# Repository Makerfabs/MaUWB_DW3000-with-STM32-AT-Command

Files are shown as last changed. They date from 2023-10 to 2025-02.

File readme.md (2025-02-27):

# MaUWB_DW3000 with STM32 AT Command

```

Version:    V1.3
Author:     Vincent
Create Date:    2023/10/14
Note:

    2023/10/19 V1.1: Add at command usage and hardware.
    2023/12/11 V1.2: Add a packaged position.py.
    2024/9/24  V1.3: MaUWB(v1.1.1).HEX is released to support simultaneous data transmission for ranging.

```
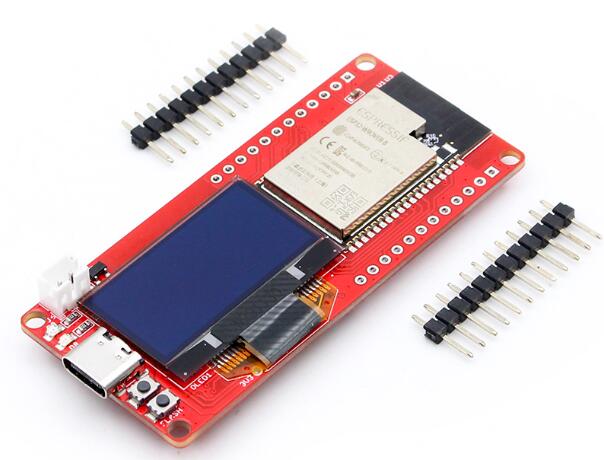
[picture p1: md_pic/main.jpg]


[toc]

# Makerfabs

[Makerfabs home page](https://www.makerfabs.com/)

[Makerfabs Wiki](https://wiki.makerfabs.com/)

# MaUWB_DW3000 with STM32 AT Command
## Intruduce

Product Link ：[MaUWB_DW3000 with STM32 AT Command](https://www.makerfabs.com/mauwb-dw3000-with-stm32-at-command.html) 

Wiki Link : [MaUWB_DW3000 with STM32 AT Command](https://wiki.makerfabs.com/%20MaUWB_DW3000-with-STM32-AT-Command.html)

The latest UWB module that solves multiple anchors& tags mutual conflicts, support max 8 Anchors + 64 tags in application, to create a multi-anchor multi-tag positioning system, and add the ability to set the Anchor antenna delay

## Feature

- DW3000 with PA, max range 500M
- Precision 0.5M(in range 100m)
- Support 8 anchors+ 64 Tags application
- Distance measurement and data transmission.

# Code

## AT Command Usage

Please refer to the AT Command manual for detailed use.

hardware\Makerfabs UWB AT Module AT Command Manual(v1.0.5).pdf

### Initial configuration

You are advised to use serial_test.ino to configure the UWB AT module.
Each time you configure the UWB AT module, follow the following configuration sequence:

```C 

AT?

//Test whether the serial port communication is normal

AT+RESTORE

//Restore factory Settings

AT+SETCFG=(x1),(x2),(x3),(x4)
// Such as: AT+SETCFG=0,1,0,1

//Set the role and frequency
//More on that later

AT+SETCAP=10,15,0

//Set the capacity and send time slot

AT+SETRPT=1

// Turn on automatic reporting

AT+SAVE

// Save

AT+RESTART

// Restart

```

### Set the role and frequency

AT+SETCFG=(x1),(x2),(x3),(x4)

Parameter description

x1: Device ID(Note: Base station 0-7, label 0-31)

x2: Device role (0: tag /1: base station)

x3: device air speed (0:850K/1:6.8M, default :6.8M)

x4: Range filtering enabled (0: off /1: on)

Generally, 850K is used and distance filtering is turned on.

```c
//Example
//A0
AT+SETCFG=0,1,0,1

//A1
AT+SETCFG=1,1,0,1

//A2
AT+SETCFG=2,1,0,1

//A3
AT+SETCFG=3,1,0,1

//T0
AT+SETCFG=0,0,0,1

//T1
AT+SETCFG=1,0,0,1

//T2
AT+SETCFG=2,0,0,1

//T3
AT+SETCFG=3,0,0,1

//T4
AT+SETCFG=4,0,0,1

//T5
AT+SETCFG=5,0,0,1

```

### Set data transmit mode

AT+SETCAP=(x1),(x2),(x3)

x1:Tag capacity (default: 10, maximum: 64)

x2:Time of a single time slot

X3:extMode (0: normal packet when communicating, 1: extended packet when communicating)

6.8M, Minimum single slot time 10ms for normal packet, Minimumsingle slot time 10ms for extended packet. 

850K. Minimum single slot time 15ms for normal packet, Minimumsingle slot time 25ms for extended packet.

```c
// 850K
AT+SETCAP=10,25,1

// 6.8M
AT+SETCAP=10,10,1

```

### Send data

Must set data transmit mode first.

AT+DATA=(x1),(x2)

x1:Length of transmitted data

x2:Transmitted data

```c

AT+DATA=32,HELLO_WORLD_123456

```

## Compiler Options

- Use type-c use cable connect USB-TTL to PC.
- Select "ESP32 DEV Module"

Libraries:
- Use 2.0.0   Wire
- Use 1.11.7   Adafruit_GFX_Library
- Use 1.14.4   Adafruit_BusIO
- Use 2.0.0   SPI
- Use 2.5.7   Adafruit_SSD1306

## Example

### esp32_at_t0

Factory firmware, reset the UWB AT module and set it to Tag 0.

### esp32_at_t0

Reset the UWB AT module and set it to Anchor 0.

### serial_test

Serial port test

### data_transmit

This command is used to test the newly added AT+DATA command, which can transmit data.

### Indoor positioning

Simple indoor positioning example, using json to pass data.
You need to configure all UWB modules in advance and burn the get_range program to A0.
This program parses the AT instructions into JSON format and uploads them through the serial port.

The corresponding Python packages, such as PySerial and PyGame, need to be installed in advance.
And modify the position of several origin points in the code:

(unit cm)
```Python

A0X, A0Y = 300, 200
A1X, A1Y = 300, 300
A2X, A2Y = 0, 0
A3X, A3Y = 0, 700

```
Connect the PC with a USB cable and run the Python program.

**This code is for promotional use only and is not part of the UWB AT module product, and Makerfabs does not provide further technical support.**

**Update**

For a more convenient experience for some customers, we provide a packaged exe file. Please insert A0 configured first, and be sure to burn the get_range program.

And make sure the computer's serial port is not connected to any other devices, because this program is scanning the first COM device.

And this program has been determined to be in the range of 10 meters by 10 meters, and will be accompanied by various crashes.

We are not responsible for any technical support for this software, for reference only, only for the packaging of position.py.

# AT Module Firmware Update

Connect ST-Link to PC.

Open STM32 ST-LINK Utility.
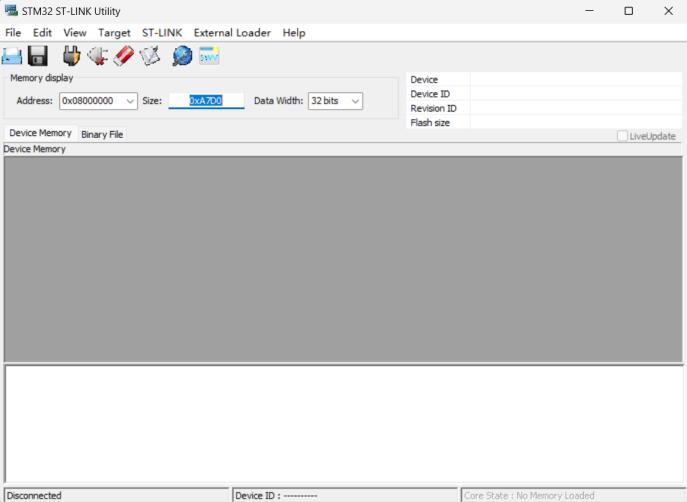
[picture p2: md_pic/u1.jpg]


Open "Target/Settings", it should display ST-Link Serial Number.
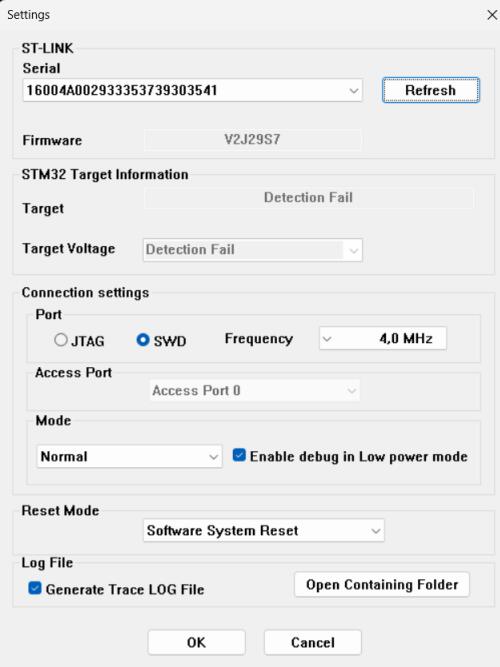
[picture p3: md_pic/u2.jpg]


Close the window, back to main page.

Connect ST-Link and MaUWB.

And use TypeC cable power on MaUWB, the power of ST-Link is not enough.

Like this:

|ST-LINK|3v3|gnd|clk|dio|
|----|----|----|----|----|
|UWB_AT|3.3v|gnd|swclk|swdio|

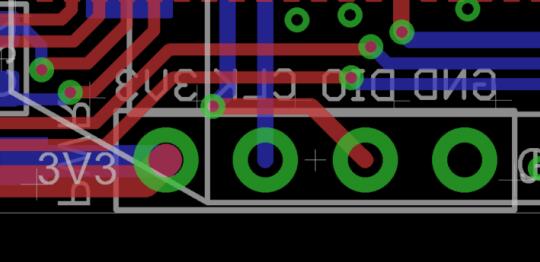
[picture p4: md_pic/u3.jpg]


Click "connect to target", it should be display device type. And click "Program verify".

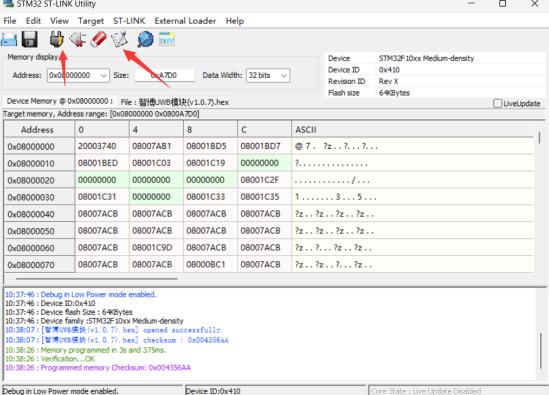
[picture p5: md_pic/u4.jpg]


Select hex file, click "START" to download.

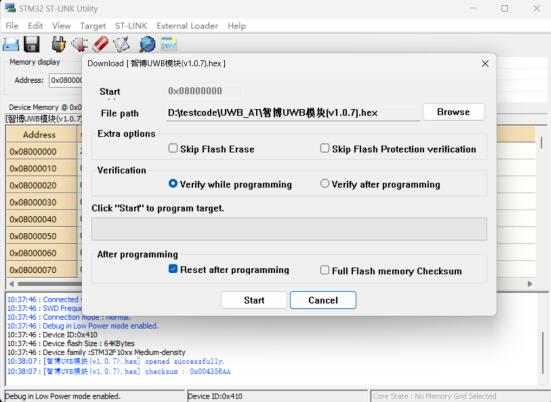
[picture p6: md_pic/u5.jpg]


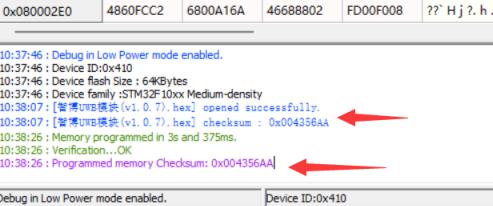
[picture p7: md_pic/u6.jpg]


# STM32 Pin Map

STM32F103RCT6

|Index|STM32|PINOUT|Function|
|----|----|----|----|
|1|PA0|DW_RSTn|Reset pin. Active Low Output.|
|2|PA4|DW_CSn|SPI chip select|
|3|PA5|DW_SLK|SPI clock|
|4|PA6|DW_MISO|SPI data output|
|5|PA7|DW_MOSI|SPI data input.|
|6|PA8|DW_EXTON|External device enable. Asserted during wake up process and held active until device enters sleep mode. Can be used to control external DC-DC converters or other circuits that are not required when the device is in sleep mode so as to minimize power consumption.|
|7|PB0|DW_wakeup|When asserted into its active high state, the WAKEUP pin brings the DW3000 out of SLEEP or DEEPSLEEP states into operational mode|
|8|PB5|DW_IRQn|Interrupt Request output from the DW3000 to the host processor. By default IRQ is an active-high output but may be configured to be active low if required. For correct operation in SLEEP and DEEPSLEEP modes it should be configured for active high operation. This pin will float in SLEEP and DEEPSLEEP states and may cause spurious interrupts unless pulled low. When the IRQ functionality is not being used the pin may be reconfigured as a general purpose I/O line, GPIO8.|
|10|PA1|LED_RUN|Indicator output pin|
|11|PA9|USART1_TX|
|12|PA10|USART1_RX|
|13|PA13|SWDIO|
|14|PA14|SWCLK|

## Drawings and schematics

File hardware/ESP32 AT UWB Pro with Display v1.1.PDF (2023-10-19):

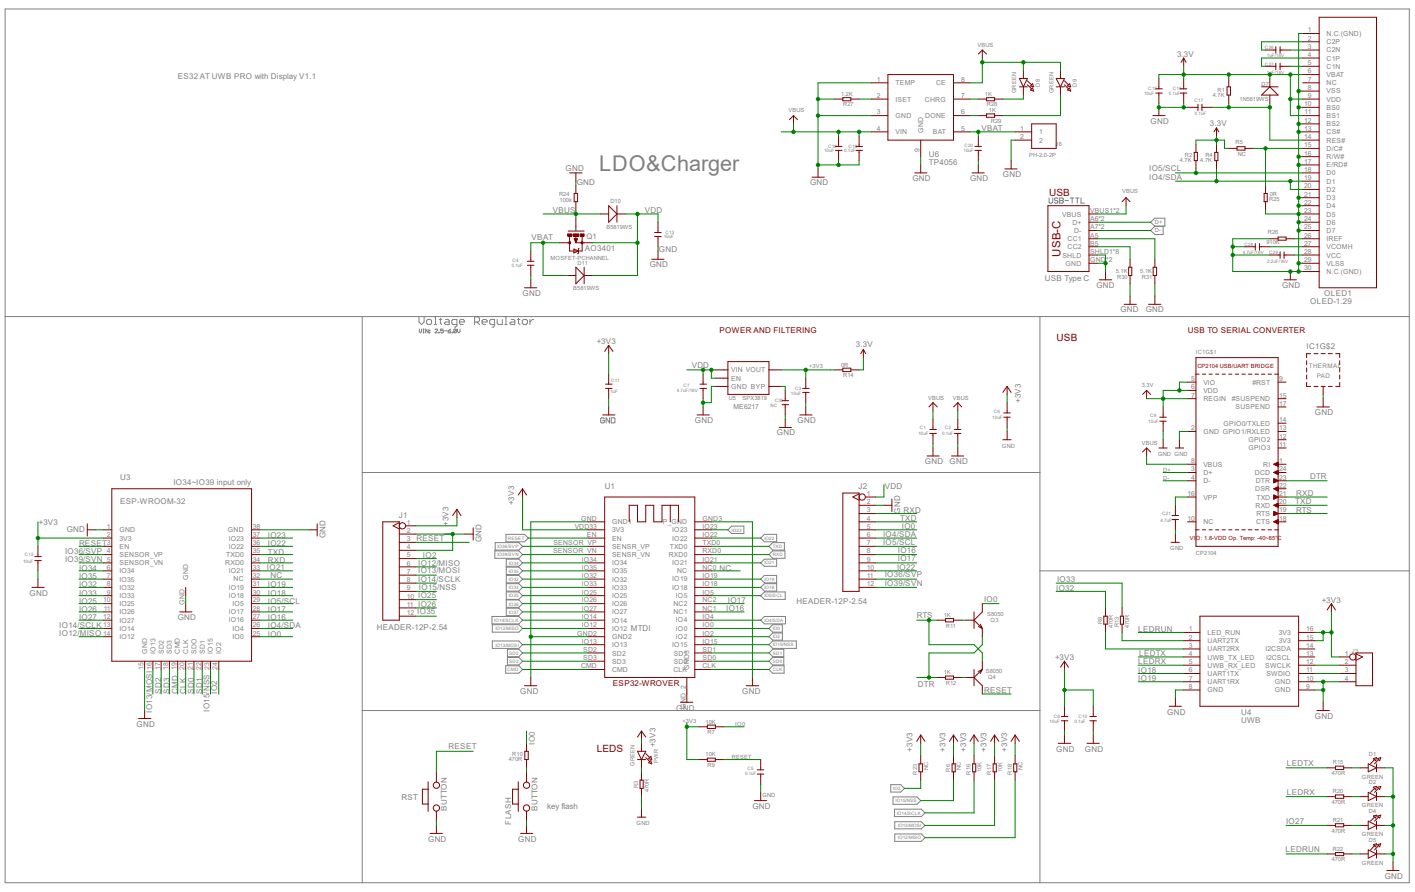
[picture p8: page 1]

ES32 AT UWB PRO with Display V1.1

USB Type C LDO&Charger

VIO: 1.8-VDD Op. Temp: -40~85°C USB⁻C

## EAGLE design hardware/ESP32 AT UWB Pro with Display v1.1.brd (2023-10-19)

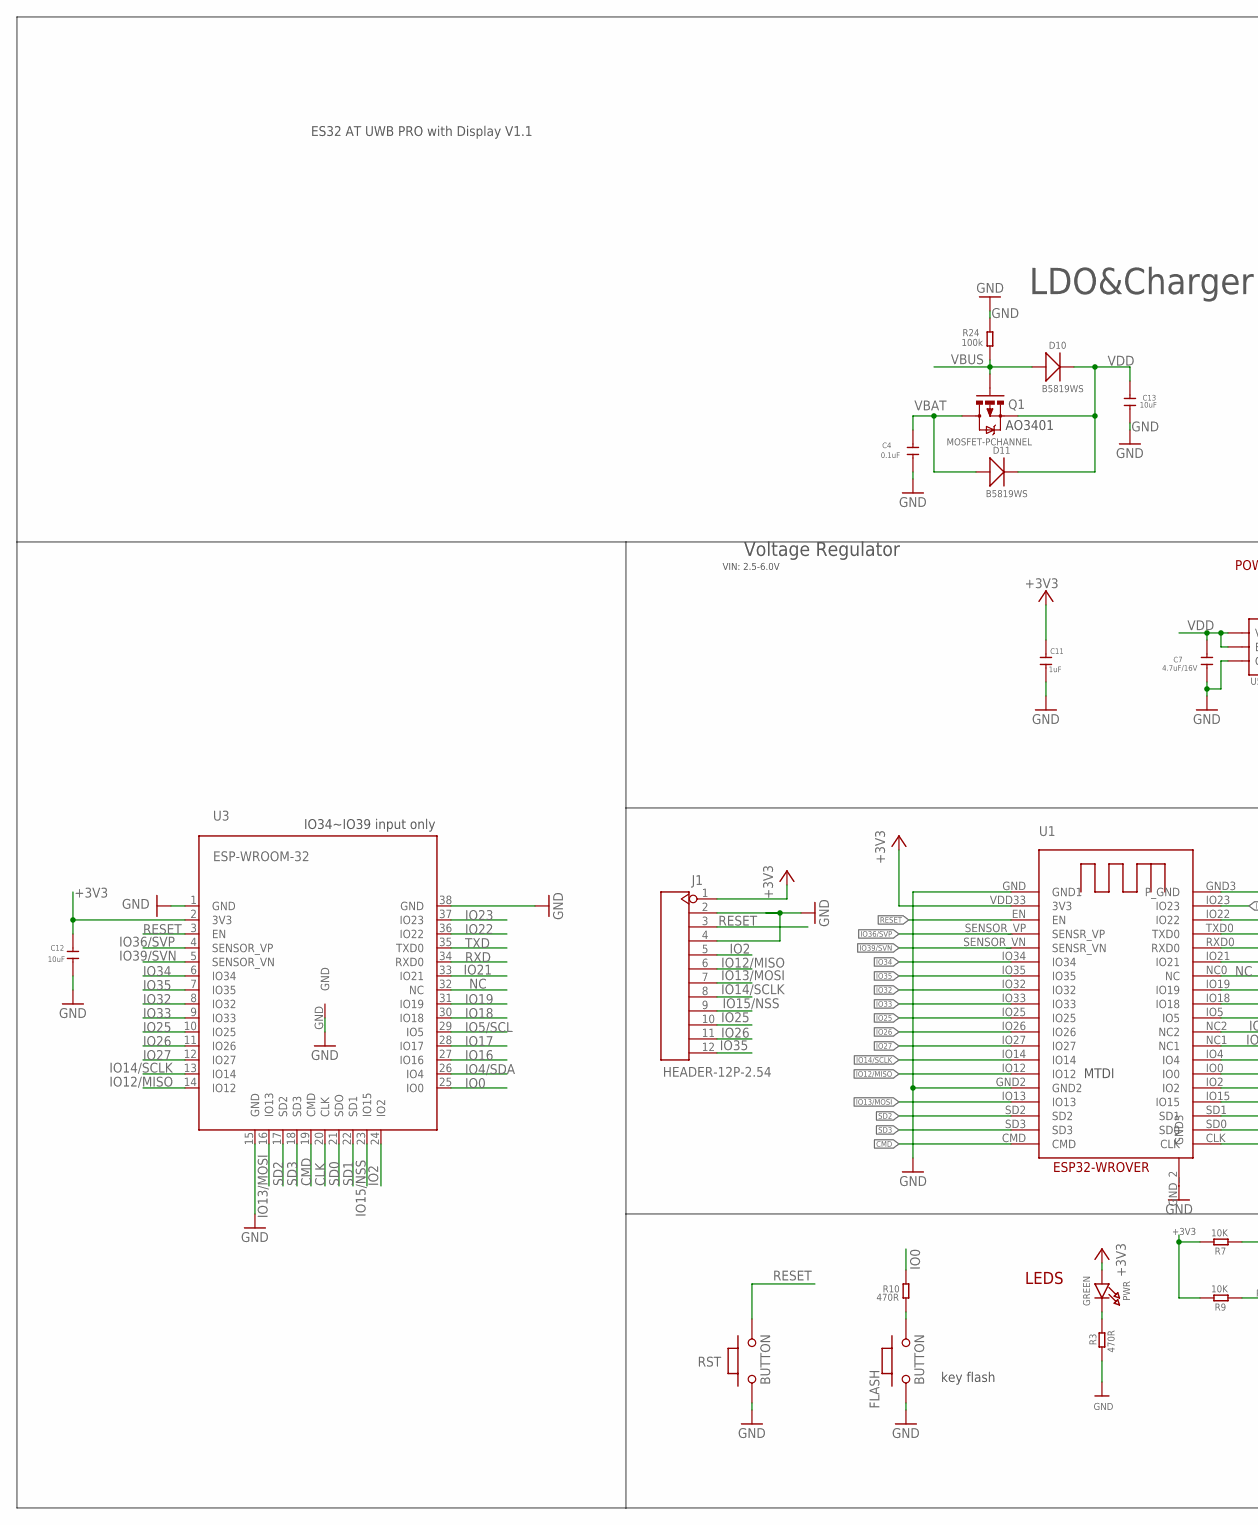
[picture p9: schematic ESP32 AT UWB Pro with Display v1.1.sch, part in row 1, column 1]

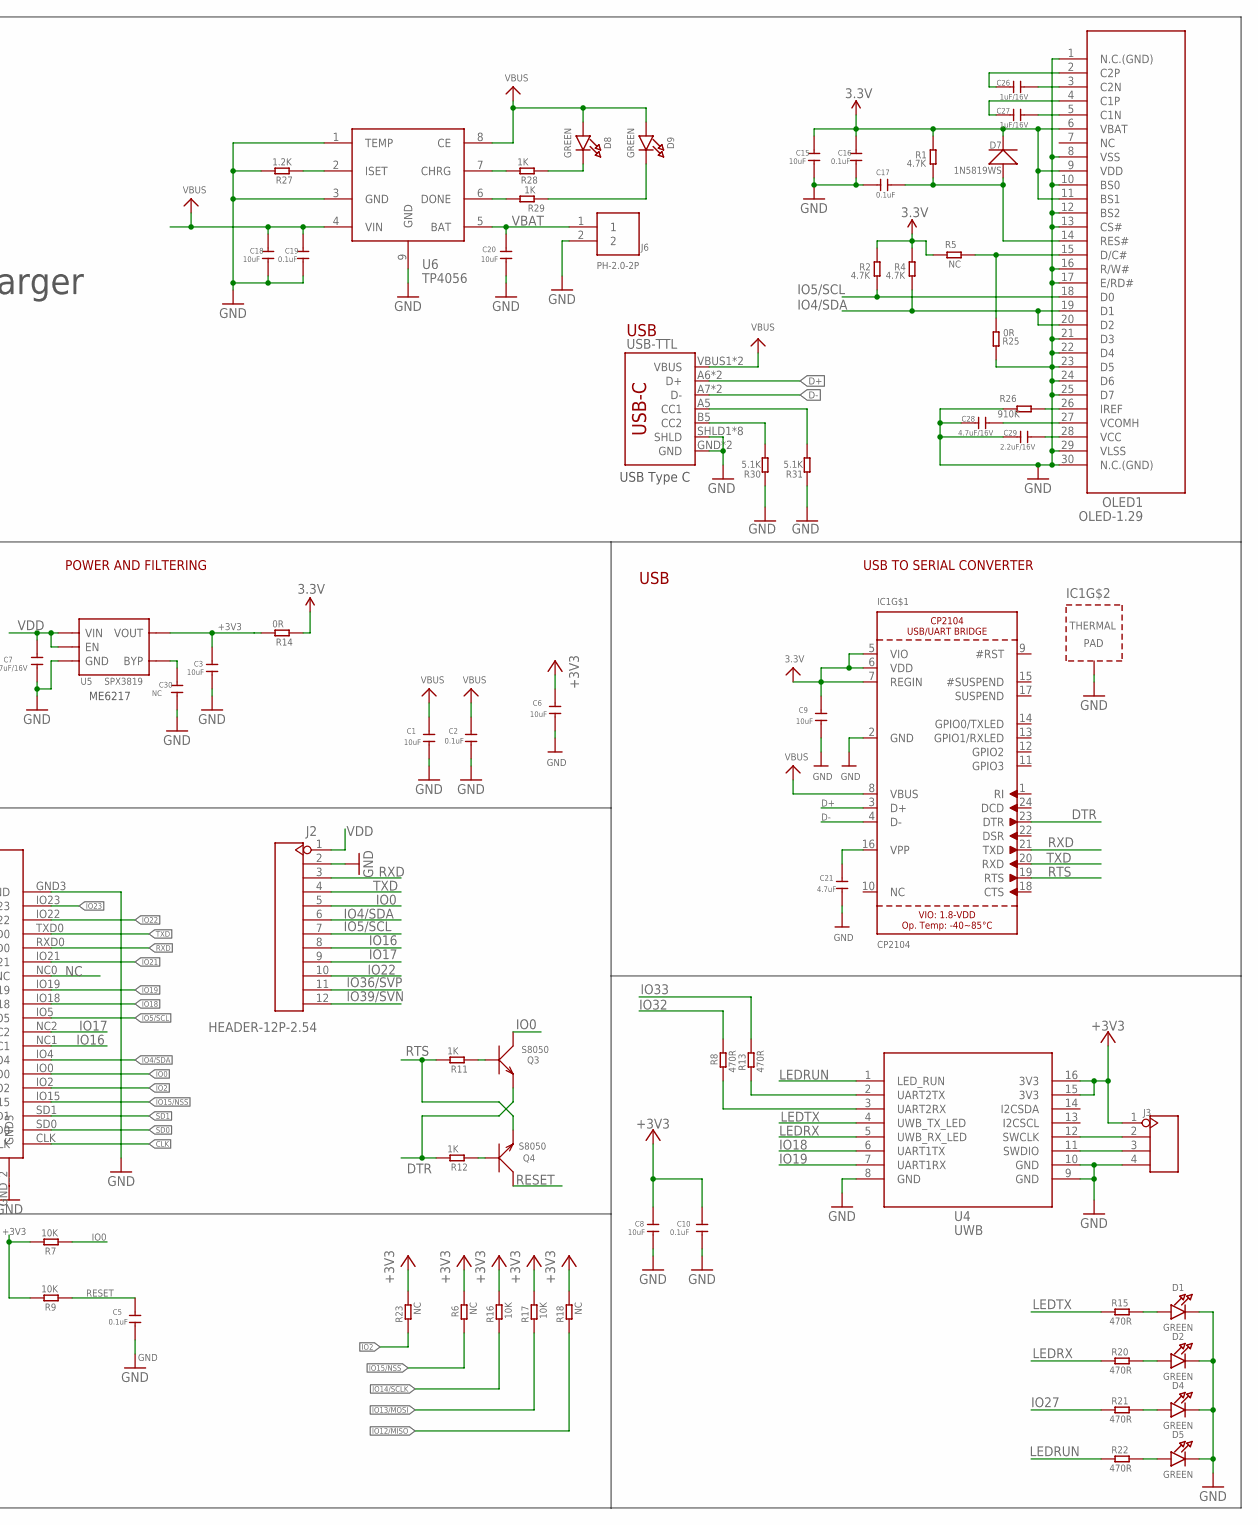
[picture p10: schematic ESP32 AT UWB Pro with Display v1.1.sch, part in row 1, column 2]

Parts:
C1, C3, C6, C8, C9, C12, C13, C15, C18, C20: 10uF; 0603
C2, C4, C5, C10, C16, C17, C19: 0.1uF; 0603
C7, C28: 4.7uF/16V; 0603
C11: 1uF; 0603
C21: 4.7uF; 0603
C26, C27: 1uF/16V; 0603
C29: 2.2uF/16V; 0603
C30: NC; 0603
D1, D2, D4, D5, D8, D9: GREEN; CHIPLED_0805_NOOUTLINE
D7: 1N5819WS; SOD323
D10, D11: B5819WS; SOD323
FLASH: BUTTON; 157SW
IC1: CP2104; QFN24_4MM_SMSC
J1, J2: HEADER-12P-2.54; 12P-2.54
J3: HEADER-4P-60/35MILROUND; 4P-65/35ROUND
J6: PH-2.0-2P
OLED1: OLED-1.29
PWR: GREEN; CHIPLED_0805_NOOUTLINE
Q1: MOSFET-PCHANNEL; SOT23-3
Q3, Q4: S8050; SOT23
R1, R2, R4: 4.7K; R0603
R3, R8, R10, R13, R15, R20, R21, R22: 470R; R0603
R5, R6, R18, R23: NC; R0603
R7, R9, R16, R17: 10K; R0603
R11, R12, R28, R29: 1K; R0603
R14, R25: 0R; R0603
R24: 100k; R0603
R26: 910K; R0603
R27: 1.2K; R0603
R30, R31: 5.1K; DISCRETE_R0603
RST: BUTTON; 157SW
U1: ESP32-WROVER
U3: ESP-WROOM-32
U4: UWB
U5: SPX3819; SOT23-5
U6: TP4056; SOP8-1.27P
USB-TTL: USB_C5; USB-C-16P-5

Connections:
3.3V: C15.1, C16.1, D7.-, OLED1.6 (VBAT), OLED1.9 (VDD), OLED1.11 (BS1), R1.2, R2.2, R4.2, R5.2, R14.1
+3V3: C3.1, C6.1, C8.1, C9.1, C10.1, C11.1, C12.1, IC1.5 (VIO), IC1.6 (VDD), IC1.7 (REGIN), J1.1, J3.1, PWR.A, R6.2, R7.2, R9.2, R14.2, R16.2, R17.2, R18.2, R23.2, U1.VDD33 (3V3), U3.2 (3V3), U4.15 (3V3), U4.16 (3V3), U5.5 (VOUT)
CLK: U1.CLK, U3.20 (CLK)
CMD: U1.CMD, U3.19 (CMD)
D+: IC1.3 (D+), USB-TTL.A6 (D+), USB-TTL.B6 (D+)
D-: IC1.4 (D-), USB-TTL.A7 (D-), USB-TTL.B7 (D-)
DTR: IC1.23 (DTR), Q3.2 (E), R12.2
GND: C1.2, C2.2, C3.2, C4.2, C5.2, C6.2, C7.2, C8.2, C9.2, C10.2, C11.2, C12.2, C13.1, C15.2, C16.2, C17.1, C18.2, C19.2, C20.2, C21.2, C28.1, C29.1, C30.2, D1.C, D2.C, D4.C, D5.C, FLASH.1, IC1.2 (GND), IC1.THERM (TP), J1.2, J1.4, J2.2, J3.4, J6.2, OLED1.1 (N.C.(GND)), OLED1.8 (VSS), OLED1.10 (BS0), OLED1.12 (BS2), OLED1.13 (CS#), OLED1.16 (R/W#), OLED1.17 (E/RD#), OLED1.21 (D3), OLED1.22 (D4), OLED1.23 (D5), OLED1.24 (D6), OLED1.25 (D7), OLED1.29 (VLSS), OLED1.30 (N.C.(GND)), R3.1, R24.2, R25.2, R26.2, R27.2, R30.1, R31.1, RST.1, U1.GND (GND1), U1.GND2, U1.GND3 (P_GND), U1.GND_2 (GND3), U3.1 (GND), U3.15 (GND), U3.38 (GND), U3.GND, U4.8 (GND), U4.9 (GND), U4.10 (GND), U5.2 (GND), U6.1 (TEMP), U6.3 (GND), U6.9 (GND), USB-TTL.GND, USB-TTL.GND2 (GND), USB-TTL.SHLD1 (SHLD), USB-TTL.SHLD2 (SHLD), USB-TTL.SHLD3 (SHLD), USB-TTL.SHLD4 (SHLD), USB-TTL.SHLD5 (SHLD), USB-TTL.SHLD6 (SHLD), USB-TTL.SHLD7 (SHLD), USB-TTL.SHLD8 (SHLD)
IO0: J2.5, Q3.3 (C), R7.1, R10.2, U1.IO0, U3.25 (IO0)
IO2: J1.5, R23.1, U1.IO2, U3.24 (IO2)
IO4/SDA: J2.6, OLED1.19 (D1), OLED1.20 (D2), R4.1, U1.IO4, U3.26 (IO4)
IO5/SCL: J2.7, OLED1.18 (D0), R2.1, U1.IO5, U3.29 (IO5)
IO12/MISO: J1.6, R18.1, U1.IO12, U3.14 (IO12)
IO13/MOSI: J1.7, R17.1, U1.IO13, U3.16 (IO13)
IO14/SCLK: J1.8, R16.1, U1.IO14, U3.13 (IO14)
IO15/NSS: J1.9, R6.1, U1.IO15, U3.23 (IO15)
IO16: J2.8, U1.NC1, U3.27 (IO16)
IO17: J2.9, U1.NC2, U3.28 (IO17)
IO18: U1.IO18, U3.30 (IO18), U4.6 (UART1TX)
IO19: U1.IO19, U3.31 (IO19), U4.7 (UART1RX)
IO21: U1.IO21, U3.33 (IO21)
IO22: J2.10, U1.IO22, U3.36 (IO22)
IO23: U1.IO23, U3.37 (IO23)
IO25: J1.10, U1.IO25, U3.10 (IO25)
IO26: J1.11, U1.IO26, U3.11 (IO26)
IO27: R21.1, U1.IO27, U3.12 (IO27)
IO32: R8.2, U1.IO32, U3.8 (IO32)
IO33: R13.2, U1.IO33, U3.9 (IO33)
IO34: U1.IO34, U3.6 (IO34)
IO35: J1.12, U1.IO35, U3.7 (IO35)
IO36/SVP: J2.11, U1.SENSOR_VP (SENSR_VP), U3.4 (SENSOR_VP)
IO39/SVN: J2.12, U1.SENSOR_VN (SENSR_VN), U3.5 (SENSOR_VN)
LEDRUN: R22.1, U4.1 (LED_RUN)
LEDRX: R20.1, U4.5 (UWB_RX_LED)
LEDTX: R15.1, U4.4 (UWB_TX_LED)
unnamed: D1.A, R15.2
unnamed: C21.1, IC1.16 (VPP)
unnamed: C17.2, D7.+, OLED1.14 (RES#), R1.1
unnamed: OLED1.15 (D/C#), R5.1, R25.1
unnamed: PWR.C, R3.2
unnamed: C28.2, OLED1.27 (VCOMH)
unnamed: C26.2, OLED1.3 (C2N)
unnamed: C29.2, OLED1.28 (VCC)
unnamed: OLED1.26 (IREF), R26.1
unnamed: R13.1, U4.2 (UART2TX)
unnamed: R8.1, U4.3 (UART2RX)
unnamed: Q4.1 (B), R12.1
unnamed: Q3.1 (B), R11.1
unnamed: FLASH.2, R10.1
unnamed: D2.A, R20.2
unnamed: D4.A, R21.2
unnamed: D5.A, R22.2
unnamed: C26.1, OLED1.2 (C2P)
unnamed: C27.1, OLED1.4 (C1P)
unnamed: C27.2, OLED1.5 (C1N)
unnamed: R27.1, U6.2 (ISET)
unnamed: R31.2, USB-TTL.A5 (CC1)
unnamed: R30.2, USB-TTL.B5 (CC2)
unnamed: J3.3, U4.11 (SWDIO)
unnamed: J3.2, U4.12 (SWCLK)
unnamed: R28.2, U6.7 (CHRG)
unnamed: R29.2, U6.6 (DONE)
unnamed: D8.C, R28.1
unnamed: D9.C, R29.1
unnamed: C30.1, U5.4 (BYP)
NC: U1.NC0 (NC), U3.32 (NC)
RESET: C5.1, J1.3, Q4.3 (C), R9.1, RST.2, U1.EN, U3.3 (EN)
RTS: IC1.19 (RTS), Q4.2 (E), R11.2
RXD: IC1.21 (TXD), J2.3, U1.RXD0, U3.34 (RXD0)
SD0: U1.SD0, U3.21 (SDO)
SD1: U1.SD1, U3.22 (SD1)
SD2: U1.SD2, U3.17 (SD2)
SD3: U1.SD3, U3.18 (SD3)
TXD: IC1.20 (RXD), J2.4, U1.TXD0, U3.35 (TXD0)
VBAT: C4.1, C20.1, D11.+, J6.1, Q1.3 (D), U6.5 (BAT)
VBUS: C1.1, C2.1, C18.1, C19.1, D8.A, D9.A, D10.+, IC1.8 (VBUS), Q1.1 (G), R24.1, U6.4 (VIN), U6.8 (CE), USB-TTL.VBUS1 (VBUS), USB-TTL.VBUS2 (VBUS)
VDD: C7.1, C13.2, D10.-, D11.-, J2.1, Q1.2 (S), U5.1 (VIN), U5.3 (EN)

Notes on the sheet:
USB
LEDS
POWER AND FILTERING
USB TO SERIAL CONVERTER
key flash
ES32 AT UWB PRO with Display V1.1
MTDI
IO34~IO39 input only
Voltage Regulator
VIN: 2.5-6.0V
USB Type C
LDO&Charger
AO3401
ME6217

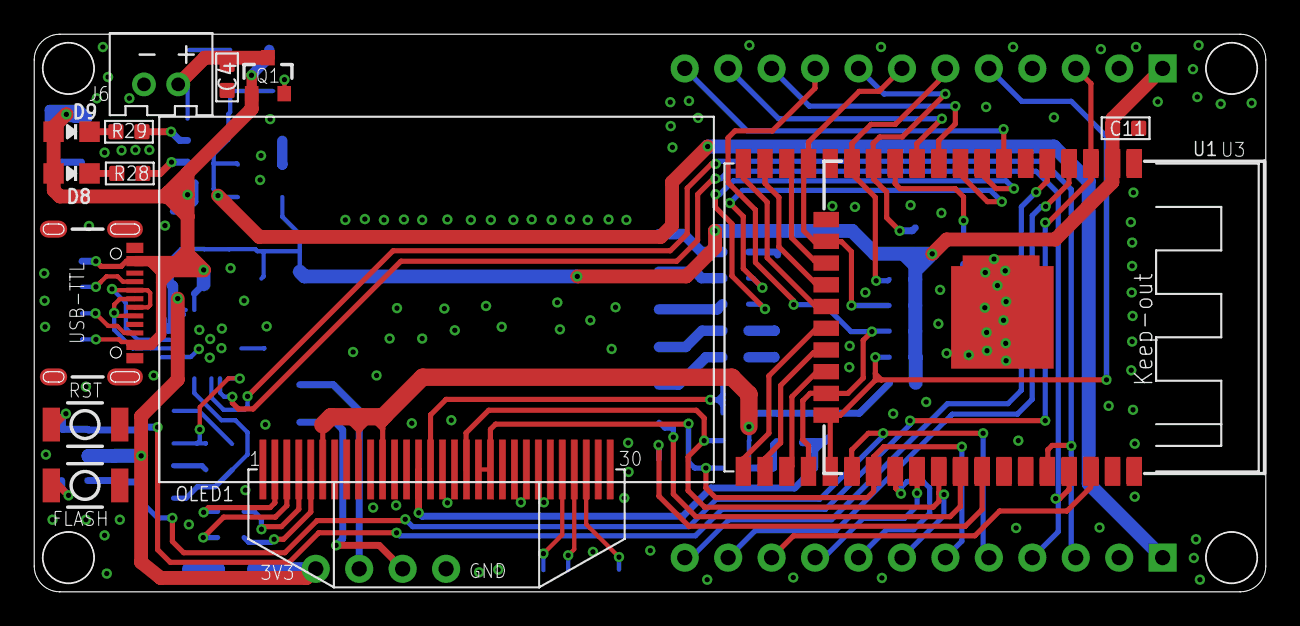
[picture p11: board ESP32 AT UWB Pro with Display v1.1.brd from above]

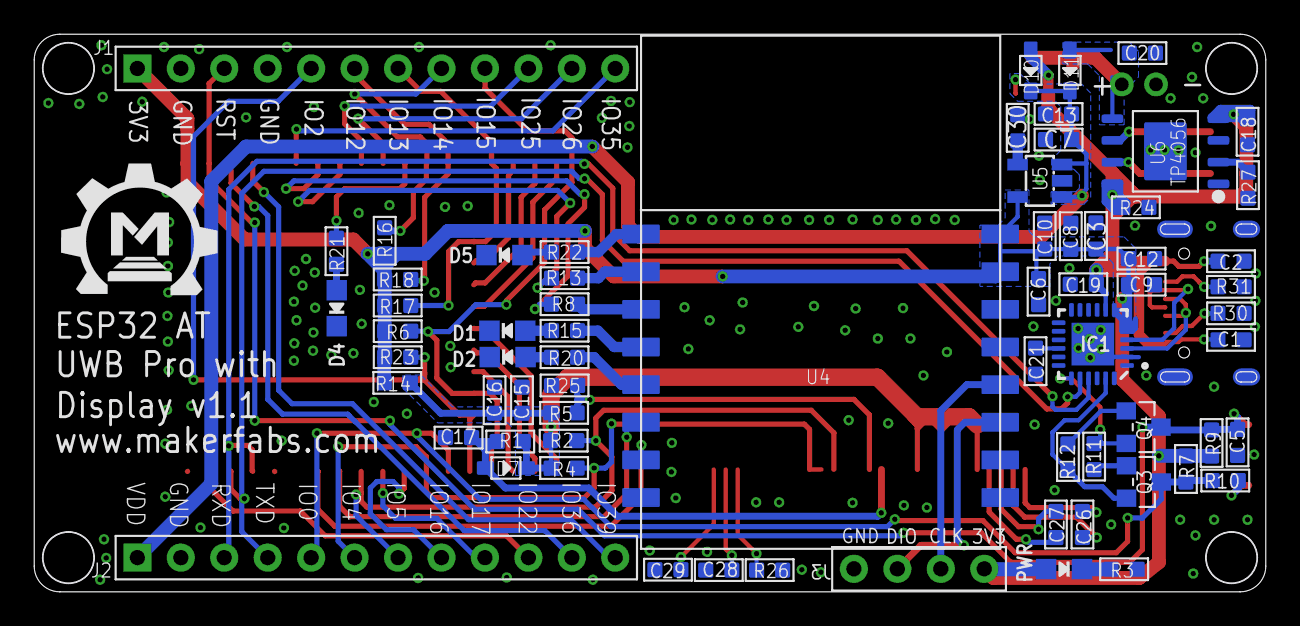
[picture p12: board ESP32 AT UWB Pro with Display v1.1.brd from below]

Board: 2 copper layers, 72.0 x 32.6 mm, 83 parts (69 on the bottom side), 77 nets.

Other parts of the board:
U$1: MAKERFABS_0.3

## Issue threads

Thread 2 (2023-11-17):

Invoking AT+RANGE command on demand

bfokin, 2023-11-17:
When installing the `esp32_at_t0` software to the anchors and a tag, the default behavior of the tag is to constantly collect the ranges between the tag and anchors.

Is there a way to disable automatic range collection  (without the use of the `AT+SLEEP` command) and only obtain ranges when invoked via programming and not performed automatically.

So, for example, I would request the ranges from the tag to all anchors one time, resulting in only one line of
`AT+RANGE=tid:0,mask:80,seq:197,range:(0,0,0,0,0,0,0,0),rssi:(0.00,0.00,0.00,0.00,0.00,0.00,0.00,0.00`
would be returned.

MassaRoddel, 2025-02-27:
I would like to know that too.
AT-RANGE is listed as a command so I expected a response from the device if I send the command.

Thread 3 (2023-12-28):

Proper usage of AT+SETANT and calibration protocol

bfokin, 2023-12-28:
Hello,

From documentation, it is not clear about what exactly AT+SETANT does.

From previous implementations of the dw3000/1000 products, calibration was performed on the anchor (meaning you would set the anchors antenna delay). In the current dw3000 with stm32-at-command implementation, it seems that you calibrate the tag's antenna delay.

In testing, when changing the antenna delay of an anchor, the resulting distance does not change. It is only when you change the tags' antenna delay do you see a change in the outputted distance.

That being said, further testing shown that, given the same tag, the antenna delay for all the anchors varied a little.

To be able to compensate, I would like to re-perform the distance calculation but it isn't posted what the calculation is for this new implementation. I would greatly appreciate the help, thank you!

scinfu, 2023-12-29:
I'm in the same situation.
@bfokin  how do you calibrate the delay?

bfokin, 2023-12-29:
Here is what I currently know. In previous implementations such as for the  [https://www.makerfabs.cc/article/esp32-uwb-antenna-delay-calibrating.html](dw1000)
the anchors are the ones that are calibrated.

from jremington's README who created the calibration demo:

> Enter the reported anchor antenna delay to the ESP32_UWB_setup_anchor code, specific for that anchor, and run that code to set up the anchor. Don't forget to set each anchor to have a unique anchor MAC address. My arbitrary naming convention is for anchors 1, 2, 3, ... to have the lowest order byte of the MAC address set to 81, 82, 83, ... and the ranging code running on the tag CURRENTLY REQUIRES them to be named accordingly.

Since the calibration process is the same for both dw3000 and dw1000 (the spec sheets are basically the same for antenna delay calibration) I tried recreating the demo that jremmington has done.

**NOTE: there was a flaw with the following that I will address below**
This was done by:

1. collecting the ranging demo for the dw3000 with stm32 AT command.
2. setting the anchor and tag to a fixed distance (record that distance in cm since the device reports in cm)
3. setting tag to index 0 and anchor to index 0.
4. parsing the data coming in from the anchor to give only the value presented in the anchor 0 slot. i.e parsing this: `AT+RANGE=tid:0,mask:01,seq:129,range:(156,0,0,0,0,0,0,0),rssi:(-82.57,0.00,0.00,0.00,0.00,0.00,0.00,0.00)`
5. modifying the antenna delay with the `AT+SETANT` command. (increase it if the distance is too far, decrease it if the distance is too short`
6. repeat if the reported distance is not equal to the distance you placed the anchor and tag.

When performing the test, what I noticed is that, when modifying the anchor antenna delay with the `AT+SETANT` function, the distance does not change. Only when I modify the tag's antenna delay does the distance actually change.

Changing the antenna delay for only the tag doesn't really make sense since the the anchor antenna delay is not the same from a given tag to all the other anchors so this is where I am stuck. Granted, on average, the distance value is much better after performing this calibration but it isn't device specific.

Hopefully that helps but there are still more questions from me.

bfokin, 2024-02-23:
@scinfu I have some good news, I reached out to support and I have a correct method of calibration.

As it should be, you must calibrate the anchors.

The calibration protocol is as followed

1. Set the anchor and tag X cm apart.
2. On the anchor, keep track of the distances for a few points
3. Compare the distance reported by the anchor and the fixed distance X.
4. Set a new antenna delay by performing the Set antenna delay command **FOLLOWED by the save command and the restart command.** The save and restart command is what was missing when I attempted calibration before.
5. Repeat steps 2 through 4 until you are within a certain degree of distance X.

With this process, I was able to calibrate the anchors for a given tag. Good Luck!

Good luck!

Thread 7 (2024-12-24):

Distance between anchors

crlgn, 2024-12-24:
Is there a built in way to detect distance between anchors? They are mostly fixed, but I need to let users do the setup themselves without hardcoding anchor positions. The only way I see at the moment is to temporarily set one anchor as a tag, get its distance from anchor 0, and set it back as anchor, then do the same for each of the others.

dataplex, 2025-01-15:
Application of the PDoA algorithms may help in this case and would require two devices here as each device has only one antenna.

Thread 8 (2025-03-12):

how  to add external antenna for better uwb and wifi reception.

gohlaysiong, 2025-03-12:
i tested the devices (4 anchors) and 1 tag in a indoor environment of 80 x 40 meter. I am able to get the location of the moving Tag, however, the uwb signal was broken or very weak if there are objects blocked in between tag and anchor. I am thinking to add external antenna to both anchors and tag to improve the connection and sign reception, is this possible ?

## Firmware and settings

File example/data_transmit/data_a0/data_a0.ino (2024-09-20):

/*
Data transmit Demo
UWB Module Firmware later than 1.1.0 is required

Use 2.0.0   Wire
Use 1.11.7   Adafruit_GFX_Library
Use 1.14.4   Adafruit_BusIO
Use 2.0.0   SPI
Use 2.5.7   Adafruit_SSD1306

*/

// User config          ------------------------------------------

#define UWB_INDEX 0

// #define TAG
#define ANCHOR

#define FREQ_850K
// #define FREQ_6800K

#define UWB_TAG_COUNT 10

// User config end       ------------------------------------------

#include <Wire.h>
#include <Adafruit_GFX.h>
#include <Adafruit_SSD1306.h>
#include <Arduino.h>

#define SERIAL_LOG Serial
#define SERIAL_AT mySerial2

HardwareSerial SERIAL_AT(2);

#define RESET 32

#define IO_RXD2 18
#define IO_TXD2 19

#define I2C_SDA 4
#define I2C_SCL 5

Adafruit_SSD1306 display(128, 64, &Wire, -1);

void setup()
{
    pinMode(RESET, OUTPUT);
    digitalWrite(RESET, HIGH);

    SERIAL_LOG.begin(115200);

    SERIAL_LOG.print(F("Hello! ESP32-S3 AT command V1.0 Test"));
    SERIAL_AT.begin(115200, SERIAL_8N1, IO_RXD2, IO_TXD2);

    SERIAL_AT.println("AT");
    Wire.begin(I2C_SDA, I2C_SCL);
    delay(1000);
    // SSD1306_SWITCHCAPVCC = generate display voltage from 3.3V internally
    if (!display.begin(SSD1306_SWITCHCAPVCC, 0x3C))
    { // Address 0x3C for 128x32
        SERIAL_LOG.println(F("SSD1306 allocation failed"));
        for (;;)
            ; // Don't proceed, loop forever
    }
    display.clearDisplay();

    logoshow();

    sendData("AT?", 2000, 1);
    sendData("AT+RESTORE", 5000, 1);

    sendData(config_cmd(), 2000, 1);
    sendData(cap_cmd(), 2000, 1);

    sendData("AT+SETRPT=0", 2000, 1);
    sendData("AT+SAVE", 2000, 1);
    sendData("AT+RESTART", 2000, 1);
}

long int runtime = 0;
int data_count = 0;

String response = "";

void loop()
{
    if ((millis() - runtime) > 1000)
    {
        char data_str[80];
        sprintf(data_str, "AT+DATA=32,UWB_A0_Data:%d", data_count * 2 + 1);
        data_count++;
        sendData(data_str, 2000, 1);
        runtime = millis();
    }

    // put your main code here, to run repeatedly:
    while (SERIAL_LOG.available() > 0)
    {
        SERIAL_AT.write(SERIAL_LOG.read());
        yield();
    }
    while (SERIAL_AT.available() > 0)
    {
        char c = SERIAL_AT.read();

        if (c == '\r')
            continue;
        else if (c == '\n' || c == '\r')
        {
            SERIAL_LOG.println(response);

            response = "";
        }
        else
            response += c;
    }
}

// SSD1306

void logoshow(void)
{
    display.clearDisplay();

    display.setTextSize(1);              // Normal 1:1 pixel scale
    display.setTextColor(SSD1306_WHITE); // Draw white text
    display.setCursor(0, 0);             // Start at top-left corner
    display.println(F("MaUWB DW3000"));

    display.setCursor(0, 20); // Start at top-left corner
    // display.println(F("with STM32 AT Command"));

    display.setTextSize(2);

    String temp = "";

#ifdef TAG
    temp = temp + "T" + UWB_INDEX;
#endif
#ifdef ANCHOR
    temp = temp + "A" + UWB_INDEX;
#endif
#ifdef FREQ_850K
    temp = temp + "   850k";
#endif
#ifdef FREQ_6800K
    temp = temp + "   6.8M";
#endif
    display.println(temp);

    display.setCursor(0, 40);

    temp = "Total: ";
    temp = temp + UWB_TAG_COUNT;
    display.println(temp);

    display.display();

    delay(2000);
}

String sendData(String command, const int timeout, boolean debug)
{
    String response = "";
    // command = command + "\r\n";

    SERIAL_LOG.println(command);
    SERIAL_AT.println(command); // send the read character to the SERIAL_LOG

    long int time = millis();

    while ((time + timeout) > millis())
    {
        while (SERIAL_AT.available())
        {

            // The esp has data so display its output to the serial window
            char c = SERIAL_AT.read(); // read the next character.
            response += c;
        }
    }

    if (debug)
    {
        SERIAL_LOG.println(response);
    }

    return response;
}

String config_cmd()
{
    String temp = "AT+SETCFG=";

    // Set device id
    temp = temp + UWB_INDEX;

    // Set device role
#ifdef TAG
    temp = temp + ",0";
#endif
#ifdef ANCHOR
    temp = temp + ",1";
#endif

    // Set frequence 850k or 6.8M
#ifdef FREQ_850K
    temp = temp + ",0";
#endif
#ifdef FREQ_6800K
    temp = temp + ",1";
#endif

    // Set range filter
    temp = temp + ",1";

    return temp;
}

String cap_cmd()
{
    String temp = "AT+SETCAP=";

    // Set Tag capacity
    temp = temp + UWB_TAG_COUNT;

    //  Time of a single time slot
#ifdef FREQ_850K
    temp = temp + ",25,1";
#endif
#ifdef FREQ_6800K
    temp = temp + ",15,1";
#endif

    return temp;
}

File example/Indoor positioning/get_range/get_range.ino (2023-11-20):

/*
For ESP32 UWB AT Demo
*/

#include <Wire.h>
#include <Adafruit_GFX.h>
#include <Adafruit_SSD1306.h>
#include <Arduino.h>

HardwareSerial mySerial2(2);

#define RESET 32

#define IO_RXD2 18
#define IO_TXD2 19

#define I2C_SDA 4
#define I2C_SCL 5

Adafruit_SSD1306 display(128, 64, &Wire, -1);

void setup()
{
    pinMode(RESET, OUTPUT);
    digitalWrite(RESET, HIGH);

    Serial.begin(115200);

    Serial.print(F("Hello! ESP32-S3 AT command V1.0 Test"));
    mySerial2.begin(115200, SERIAL_8N1, IO_RXD2, IO_TXD2);

    mySerial2.println("AT");
    Wire.begin(I2C_SDA, I2C_SCL);
    delay(1000);
    // SSD1306_SWITCHCAPVCC = generate display voltage from 3.3V internally
    if (!display.begin(SSD1306_SWITCHCAPVCC, 0x3C))
    { // Address 0x3C for 128x32
        Serial.println(F("SSD1306 allocation failed"));
        for (;;)
            ; // Don't proceed, loop forever
    }
    display.clearDisplay();

    logoshow();
}

long int runtime = 0;

String response = "";
String rec_head = "AT+RANGE";

void loop()
{

    // put your main code here, to run repeatedly:
    while (Serial.available() > 0)
    {
        mySerial2.write(Serial.read());
        yield();
    }
    while (mySerial2.available() > 0)
    {
        char c = mySerial2.read();

        if (c == '\r')
            continue;
        else if (c == '\n' || c == '\r')
        {
            // if(0)
            if (response.indexOf(rec_head) != -1)
            {

                range_analy(response);

                // Serial.println("-----------Get range msg-----------");

                // String result = response.substring(response.indexOf(rec_head) + rec_head.length());

                // Serial.println(result);
                // Serial.println("-----------Over-----------");
            }
            else
            {
                Serial.println(response);
            }

            response = "";
        }
        else
            response += c;
    }
}

// SSD1306

void logoshow(void)
{
    display.clearDisplay();

    display.setTextSize(2);              // Normal 1:1 pixel scale
    display.setTextColor(SSD1306_WHITE); // Draw white text
    display.setCursor(0, 0);             // Start at top-left corner
    display.println(F("Get Range"));

    // display.setTextSize(1);
    display.setCursor(0, 20);
    display.println(F("JSON"));
    display.setCursor(0, 40);
    display.println(F("A0"));
    display.display();
    delay(2000);
}

// AT+RANGE=tid:1,mask:04,seq:63,range:(0,0,30,0,0,0,0,0),rssi:(0.00,0.00,-77.93,0.00,0.00,0.00,0.00,0.00)

void range_analy(String data)
{
    String id_str = data.substring(data.indexOf("tid:") + 4, data.indexOf(",mask:"));
    String range_str = data.substring(data.indexOf("range:"), data.indexOf(",rssi:"));
    String rssi_str = data.substring(data.indexOf("rssi:"));

    // Serial.println(id_str);
    // Serial.println(range_str);
    // Serial.println(rssi_str);

    // range:(0,0,51,0,0,0,0,0)
    // rssi:(0.00,0.00,-78.54,0.00,0.00,0.00,0.00,0.00)

    int range_list[8];
    double rssi_list[8];
    int count = 0;

    count = sscanf(range_str.c_str(), "range:(%d,%d,%d,%d,%d,%d,%d,%d)",
                   &range_list[0], &range_list[1], &range_list[2], &range_list[3],
                   &range_list[4], &range_list[5], &range_list[6], &range_list[7]);

    if (count != 8)
    {
        Serial.println("RANGE ANALY ERROR");
        Serial.println(count);
        return;
    }

    count = sscanf(rssi_str.c_str(), "rssi:(%lf,%lf,%lf,%lf,%lf,%lf,%lf,%lf)",
                   &rssi_list[0], &rssi_list[1], &rssi_list[2], &rssi_list[3],
                   &rssi_list[4], &rssi_list[5], &rssi_list[6], &rssi_list[7]);

    if (count != 8)
    {
        Serial.println("RSSI ANALY ERROR");
        Serial.println(count);
        return;
    }

    // Serial Port
    // Serial.print("TAG ");
    // Serial.println(id_str);
    // for (int i = 0; i < 8; i++)
    // {
    //     Serial.print("A");
    //     Serial.print(i);
    //     Serial.print(" RANGE ");
    //     Serial.print(range_list[i]);
    //     Serial.print(" RSSI ");
    //     Serial.println(rssi_list[i]);
    // }

    // Serial Port Json
    String json_str = "";
    json_str = json_str + "{\"id\":" + id_str + ",";
    json_str = json_str + "\"range\":[";
    for (int i = 0; i < 8; i++)
    {
        if (i != 7)
            json_str = json_str + range_list[i] + ",";
        else
            json_str = json_str + range_list[i] + "]}";
    }

    Serial.println(json_str);
}

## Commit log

2023-10-19 Add hardware and at command usage
    [ESP32 AT UWB Pro with Display v1.1.brd, ESP32 AT UWB Pro with Display v1.1.sch]
2025-02-27 Update
    添加两条新AT指令

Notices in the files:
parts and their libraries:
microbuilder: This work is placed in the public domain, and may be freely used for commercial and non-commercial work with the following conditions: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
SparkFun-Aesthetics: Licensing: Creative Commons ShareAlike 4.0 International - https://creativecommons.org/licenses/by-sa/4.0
